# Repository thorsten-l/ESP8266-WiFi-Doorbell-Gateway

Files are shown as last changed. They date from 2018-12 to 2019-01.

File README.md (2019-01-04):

# ESP8266-WiFi-Doorbell-Gateway
A gateway for your doorbell button ;-)

## Screenshots
Find screenshots of the web interface in the [docs](https://github.com/thorsten-l/ESP8266-WiFi-Doorbell-Gateway/tree/master/docs) directory.

## Schematic diagrams and PCB files
Find schematic diagrams and pcb files in the [kicad](https://github.com/thorsten-l/ESP8266-WiFi-Doorbell-Gateway/tree/master/kicad) directory.

## Precompiled Firmware
Find the precompiled firmware in the [firmware](https://github.com/thorsten-l/ESP8266-WiFi-Doorbell-Gateway/tree/master/firmware) directory.

## Compile
This is a [PlatformIO](https://platformio.org/) project.

## Firmware Reset
1. Power on the WiFi Doorbell Gateway
2. Press down and hold the Power-Button during the first 5s
3. Release Power-Button when the WiFi LED starts rapidly fast blinking
4. The firmware reset ends after about 30s indicated by a permanent WiFi LED on.

## Default Settings
After a firmware reset the following values are set.

| | value | description |
|----|---|---|
| WiFi SSID | DoorbellGW-`esp id` | SSID in accesspoint mode |
| IP Address | 192.168.192.1 | ip address in accesspoint mode |
| Admin password | admin | Setup admin password |
| OTA Hostname | doorbell-gateway-1 | *O*ver *T*he *A*ir hostname |
| OTA Password | otapass | OTA firmware upload password |
| OpenHAB Callback Enabled | **false** | |
| OpenHAB Version | 1 | Callback for OpenHAB version 1 or 2 |
| OpenHAB Item Name | DoorbellGateway1 | |
| OpenHAB Host | 192.168.1.1 | |
| OpenHAB Port | 80 | |
| OpenHAB Use Authentication | false | |
| OpenHAB User | user |  |
| OpenHAB Password | password | |
| MQTT Enabled | **false** |  |
| MQTT ClientId | DoorbellGateway1 |  |
| MQTT Host | 192.168.1.1 | |
| MQTT Port | 80 | |
| MQTT Use Authentication | false | |
| MQTT User | user |  |
| MQTT Password | password | |
| MQTT Out Topic | doorbell1/out | sending callback |
| Syslog Enabled | **false** |  |
| Syslog Host | 192.168.1.1 | |
| Syslog Port (TCP) | 80 | |
| Syslog App Name | gateway-doorbell |  |

## Documentation
- Find screenshots of the web-pages [here](https://github.com/thorsten-l/ESP8266-WiFi-Doorbell-Gateway/tree/master/docs)

## Hardware
- [WEMOS D1 mini](https://wiki.wemos.cc/products:d1:d1_mini)

## References
- [PlatformIO](https://platformio.org/)
- [Arduino core for ESP8266 WiFi chip](https://github.com/esp8266/Arduino)
- [Async TCP Library for ESP8266](https://github.com/me-no-dev/ESPAsyncTCP)
- [Async Web Server for ESP8266 and ESP32](https://github.com/me-no-dev/ESPAsyncWebServer)
- [Arduino-pubsubclient - A client library for the ESP8266 that provides support for MQTT](https://github.com/heman4t/Arduino-pubsubclient)
- [Pure.CSS - A nice CSS, as GZIP it is less than 4k so it is useful for embedded devices](https://purecss.io/)

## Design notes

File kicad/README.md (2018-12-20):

# Schematic Diagram and PCB files

## Program
These files are created with [KiCad EDA](http://kicad-pcb.org/).

## Schematic Diagrams
- [WiFi Doorbell Gateway](https://github.com/thorsten-l/ESP8266-WiFi-Doorbell-Gateway/blob/master/kicad/wifidoorbell/WifiDoorBell-D1-mini.pdf)
- [WiFi LED Button](https://github.com/thorsten-l/ESP8266-WiFi-Doorbell-Gateway/blob/master/kicad/wifiledbutton/WifiLedButton.pdf)

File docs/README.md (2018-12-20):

# Documentation
## Screenshots
### Home Page
Klick on top right bars to open menu.
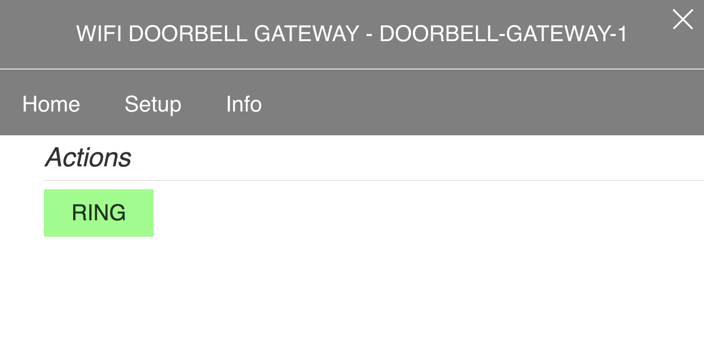
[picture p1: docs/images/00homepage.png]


### Setup Page

Admin password
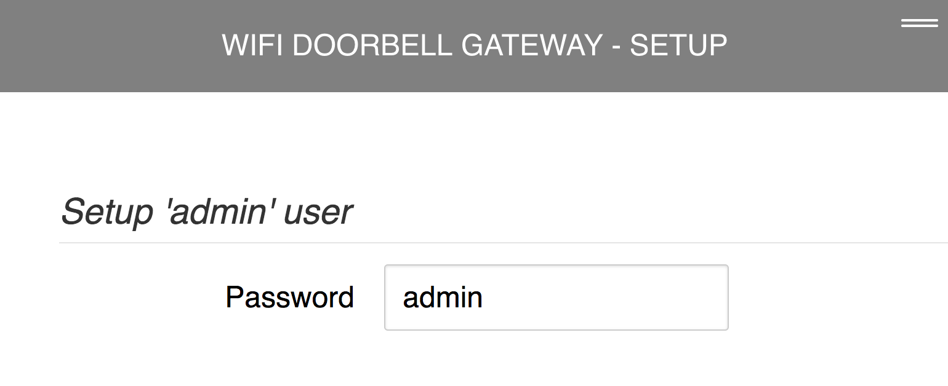
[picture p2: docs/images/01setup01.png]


Wifi Settings
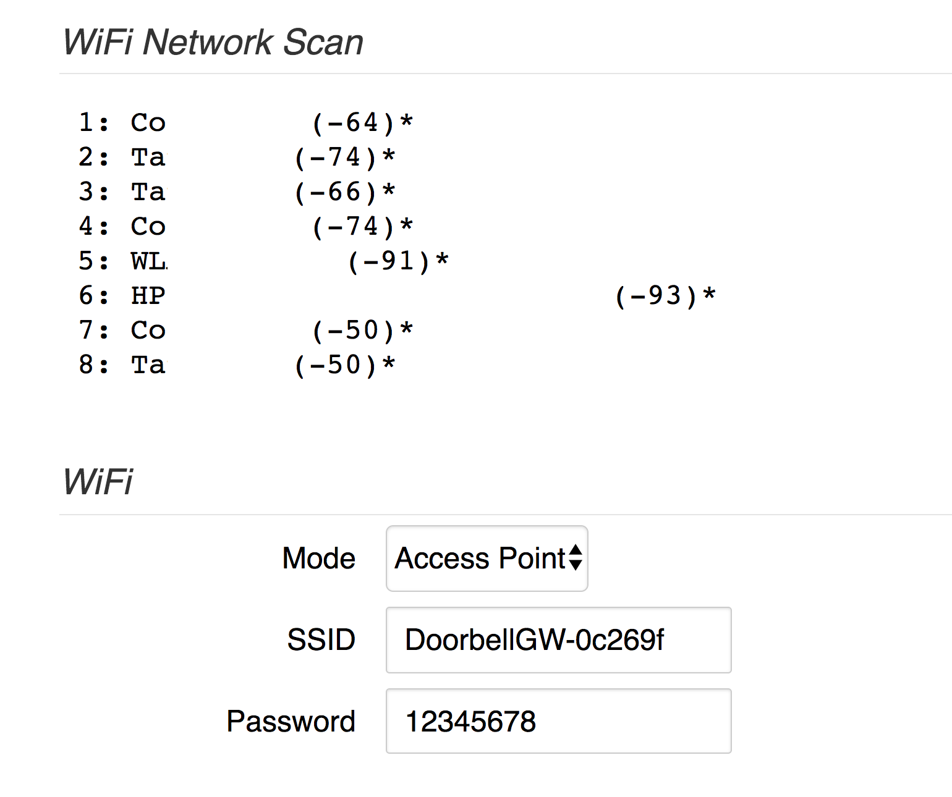
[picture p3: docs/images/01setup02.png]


Network Settings
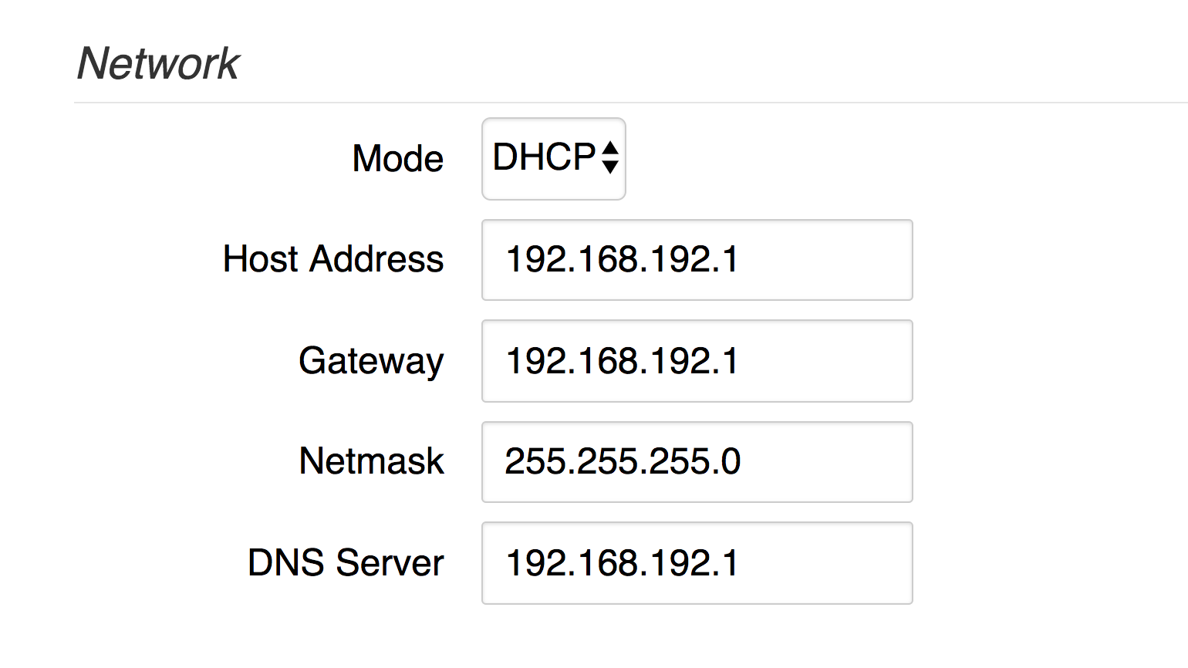
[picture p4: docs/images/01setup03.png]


OTA Settings
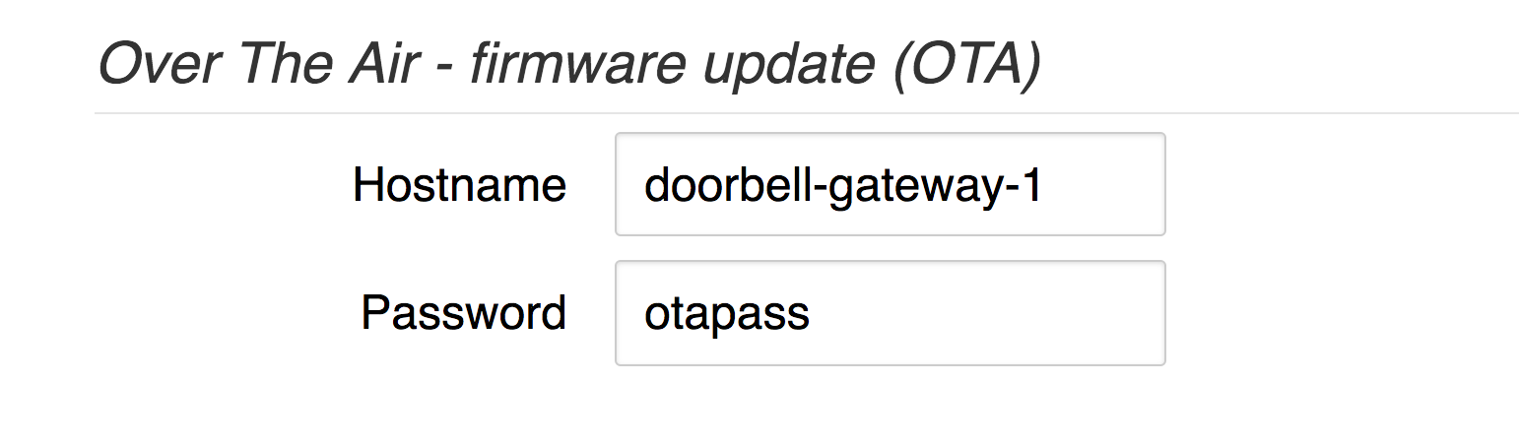
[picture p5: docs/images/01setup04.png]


OpenHAB Settings
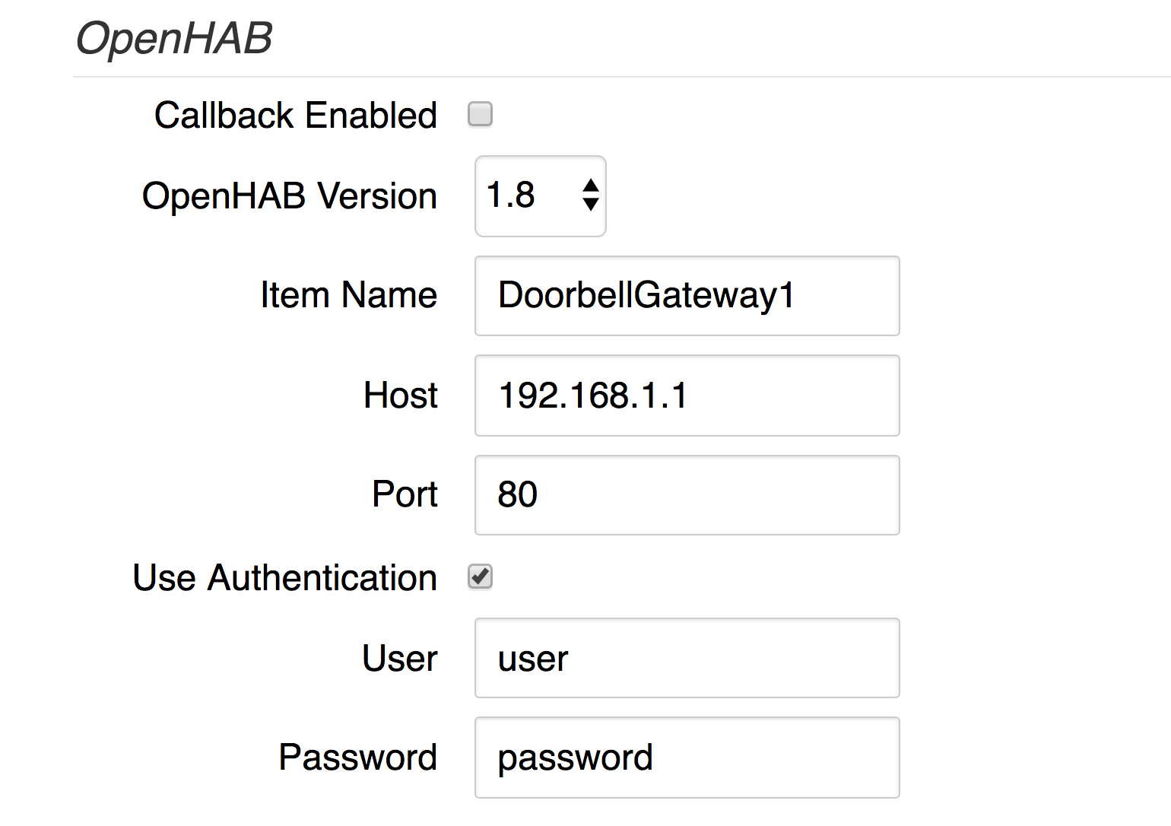
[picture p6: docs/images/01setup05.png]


MQTT Settings
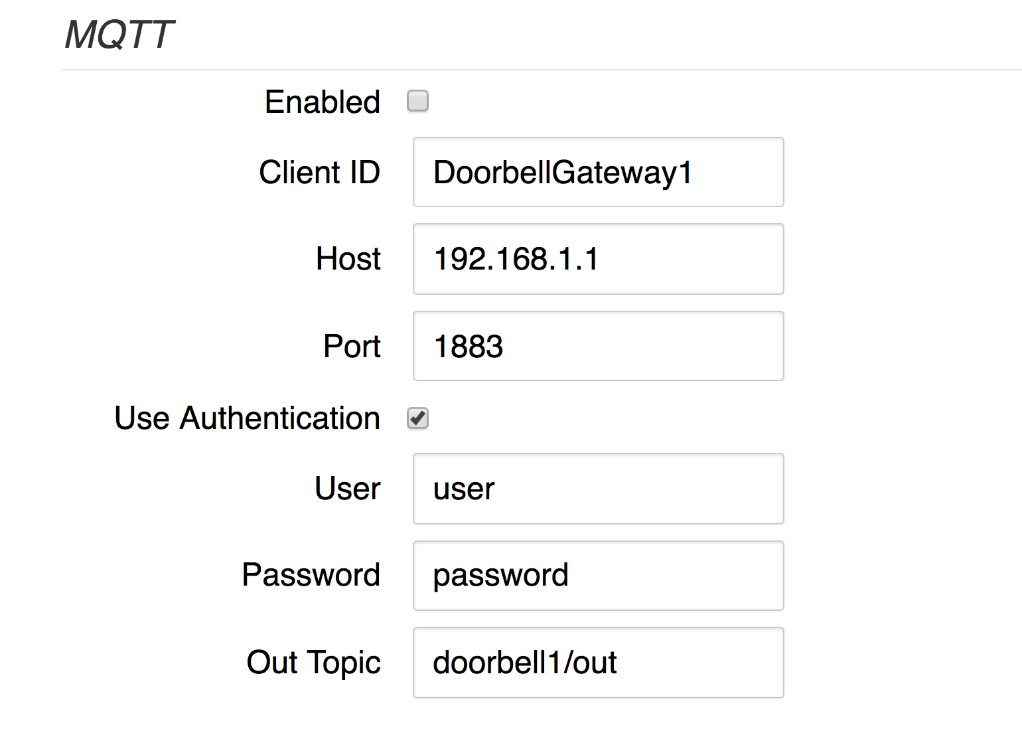
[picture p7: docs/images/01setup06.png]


Syslog Settings
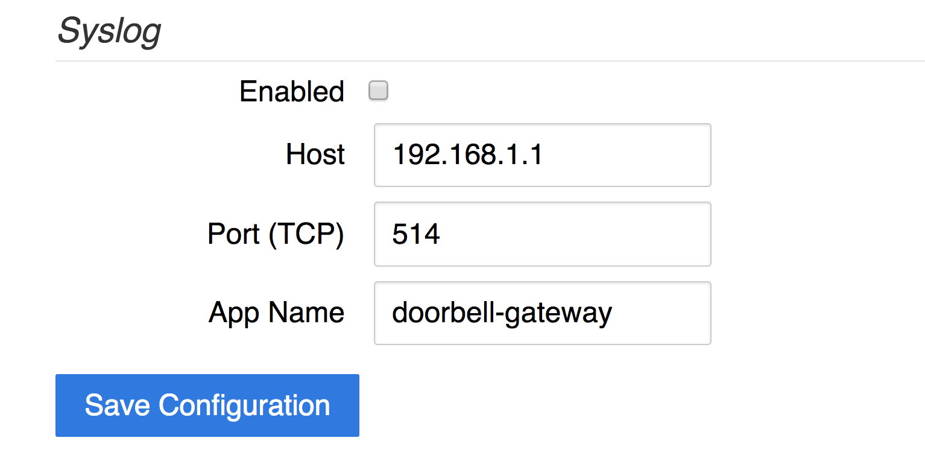
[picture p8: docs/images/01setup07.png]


## Info Page
Application, RESTful and Build information
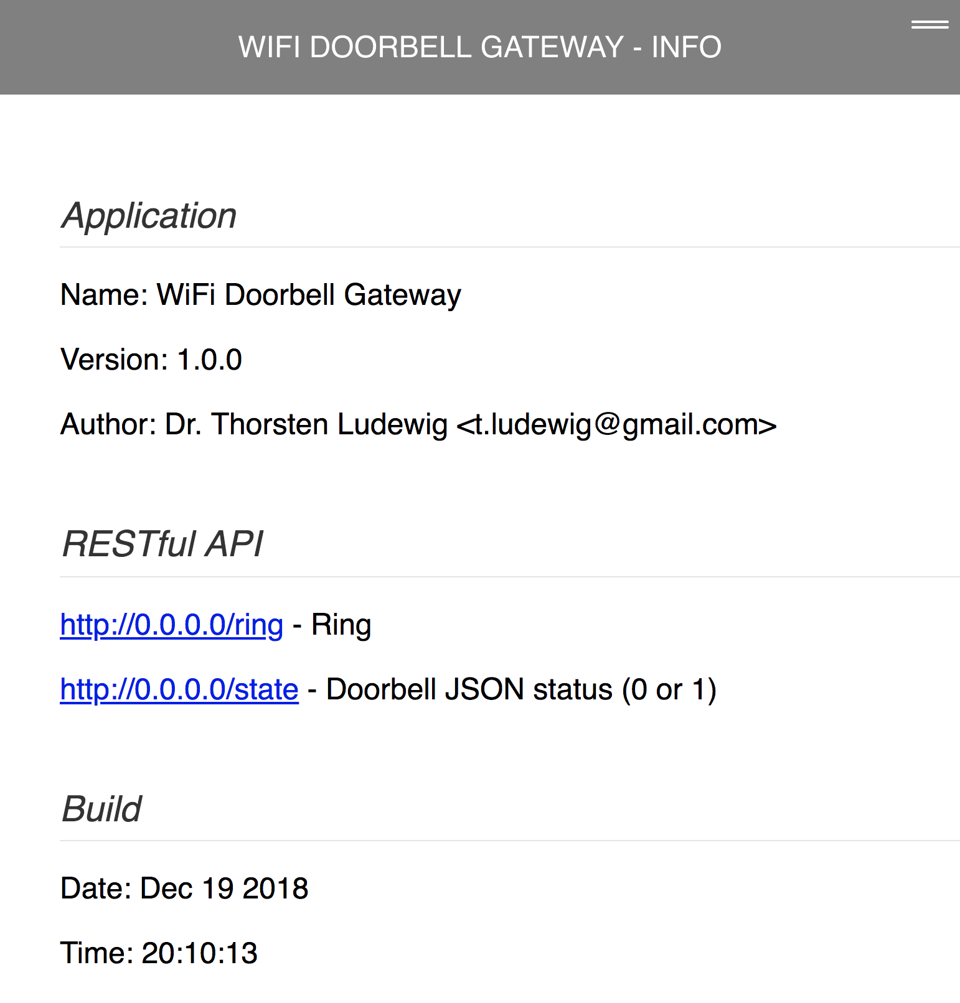
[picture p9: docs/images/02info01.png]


Services information
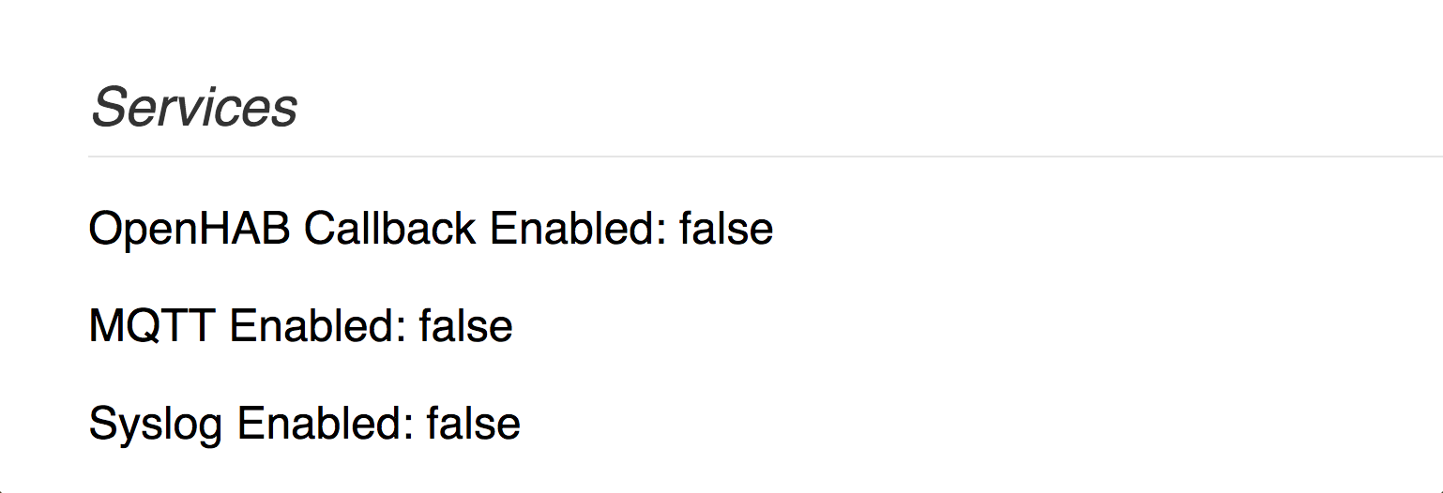
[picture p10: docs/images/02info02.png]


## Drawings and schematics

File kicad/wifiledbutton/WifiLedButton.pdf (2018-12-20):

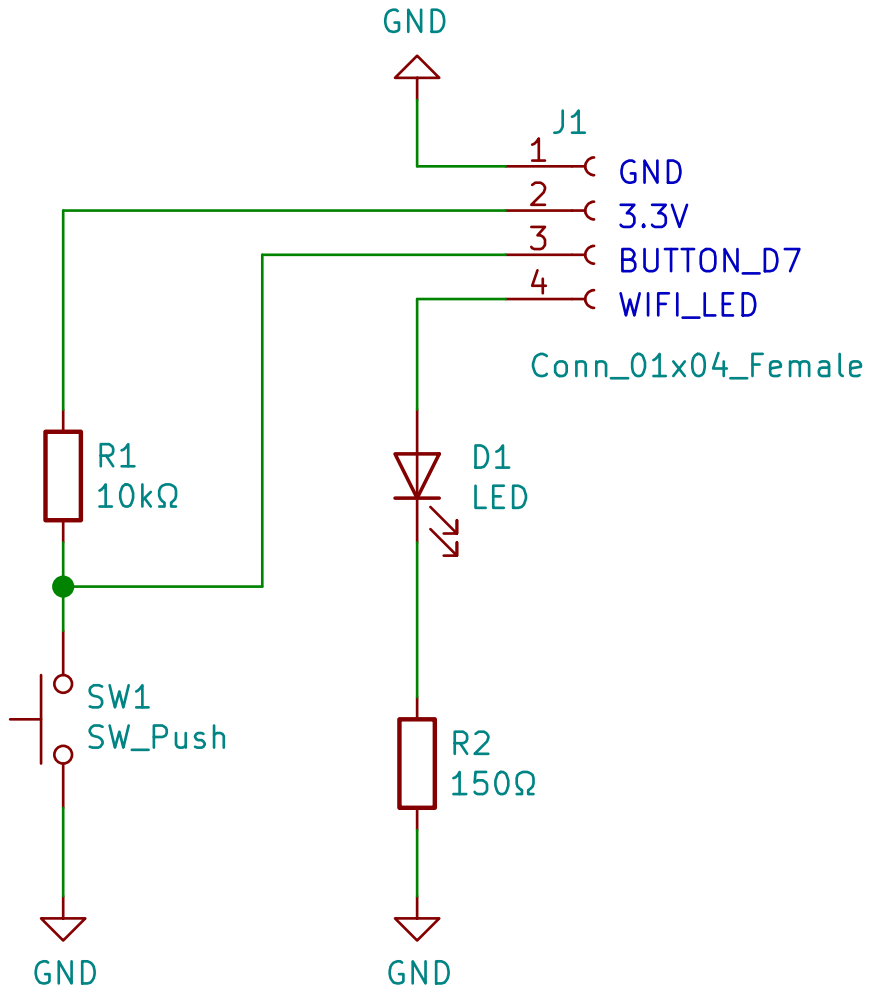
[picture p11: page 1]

File: WifiLedButton.sch Sheet: / Dr.-Ing. Thorsten Ludewig D1
LED

Id: 1/1 Title: Wifi LED Button

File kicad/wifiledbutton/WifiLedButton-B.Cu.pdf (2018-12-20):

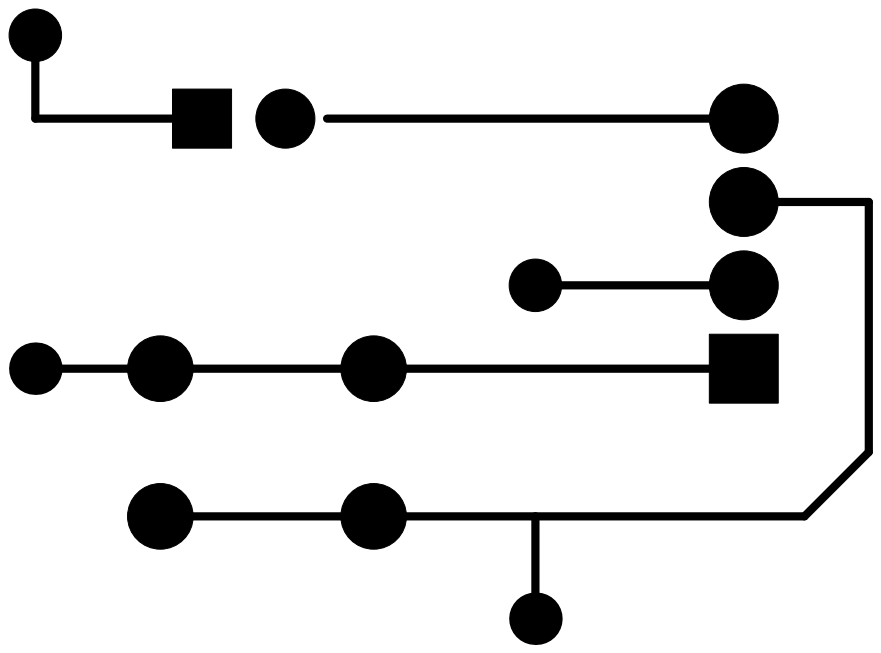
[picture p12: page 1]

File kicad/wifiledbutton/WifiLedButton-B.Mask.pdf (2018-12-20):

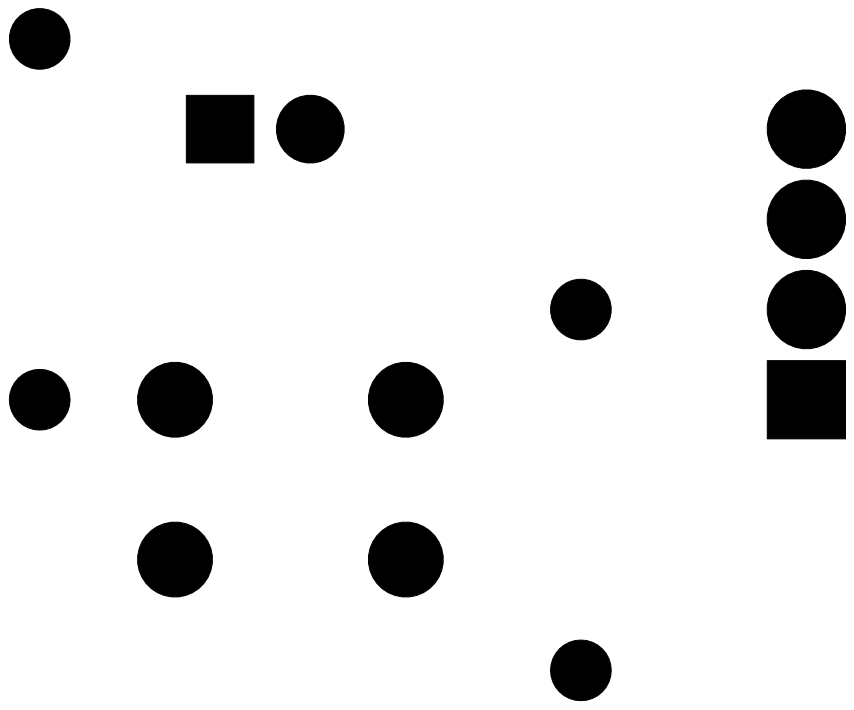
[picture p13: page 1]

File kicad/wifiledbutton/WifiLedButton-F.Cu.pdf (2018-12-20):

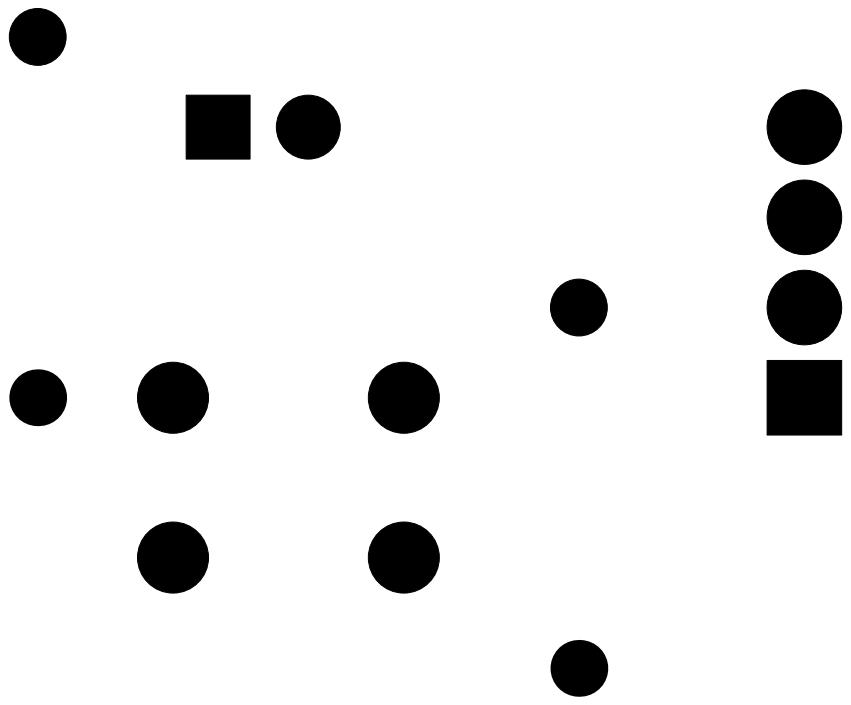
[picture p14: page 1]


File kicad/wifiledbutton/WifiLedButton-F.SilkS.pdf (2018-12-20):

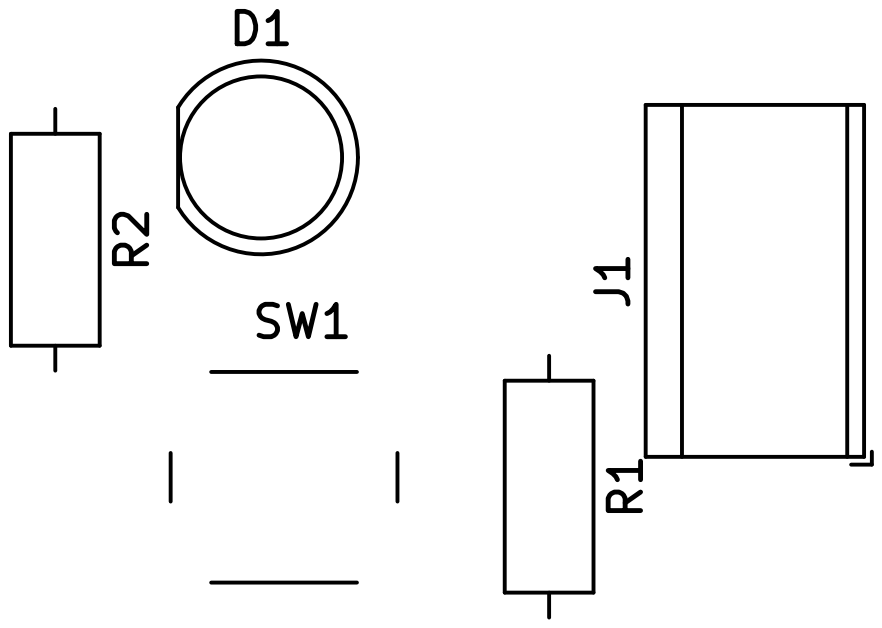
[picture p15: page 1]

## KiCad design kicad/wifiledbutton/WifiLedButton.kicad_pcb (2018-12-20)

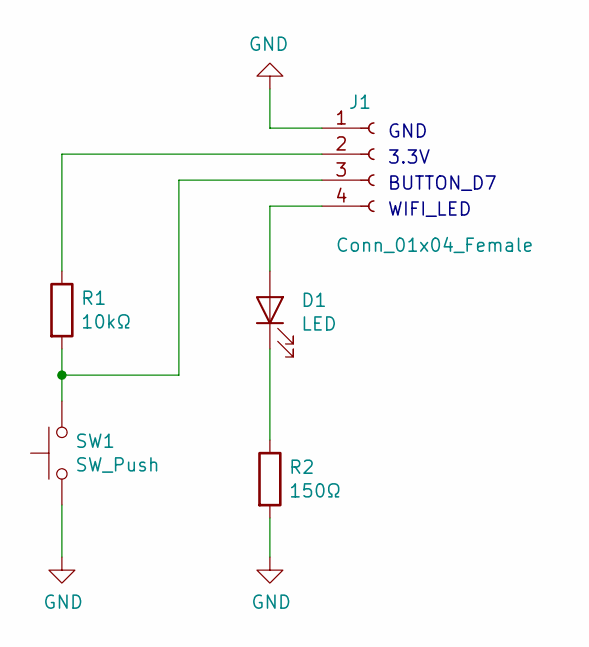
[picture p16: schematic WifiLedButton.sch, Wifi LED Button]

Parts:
D1: LED; LED_D5.0mm
J1: Conn_01x04_Female; TerminalBlock_TE_282834-4_1x04_P2.54mm_Horizontal
R1: 10kΩ; R_Axial_DIN0207_L6.3mm_D2.5mm_P10.16mm_Horizontal
R2: 150Ω; R_Axial_DIN0207_L6.3mm_D2.5mm_P10.16mm_Horizontal
SW1: SW_Push; SW_PUSH_6mm

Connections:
GND: J1.1, R2.2, SW1.1
unnamed: D1.1 (K), R2.1
unnamed: D1.2 (A), J1.4
unnamed: J1.2, R1.1
unnamed: J1.3, R1.2, SW1.2

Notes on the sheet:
GND
3.3V
BUTTON_D7
WIFI_LED

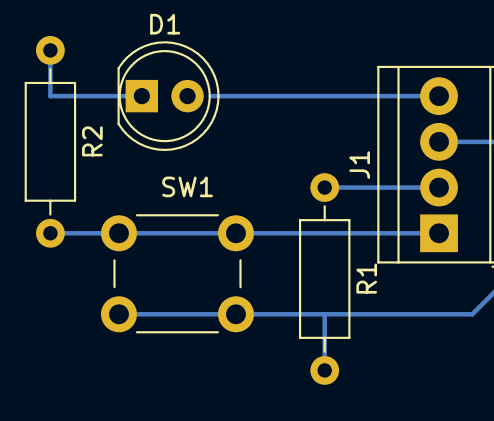
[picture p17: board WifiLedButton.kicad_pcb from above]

Board: 2 copper layers, 5 parts (0 on the bottom side), 5 nets.

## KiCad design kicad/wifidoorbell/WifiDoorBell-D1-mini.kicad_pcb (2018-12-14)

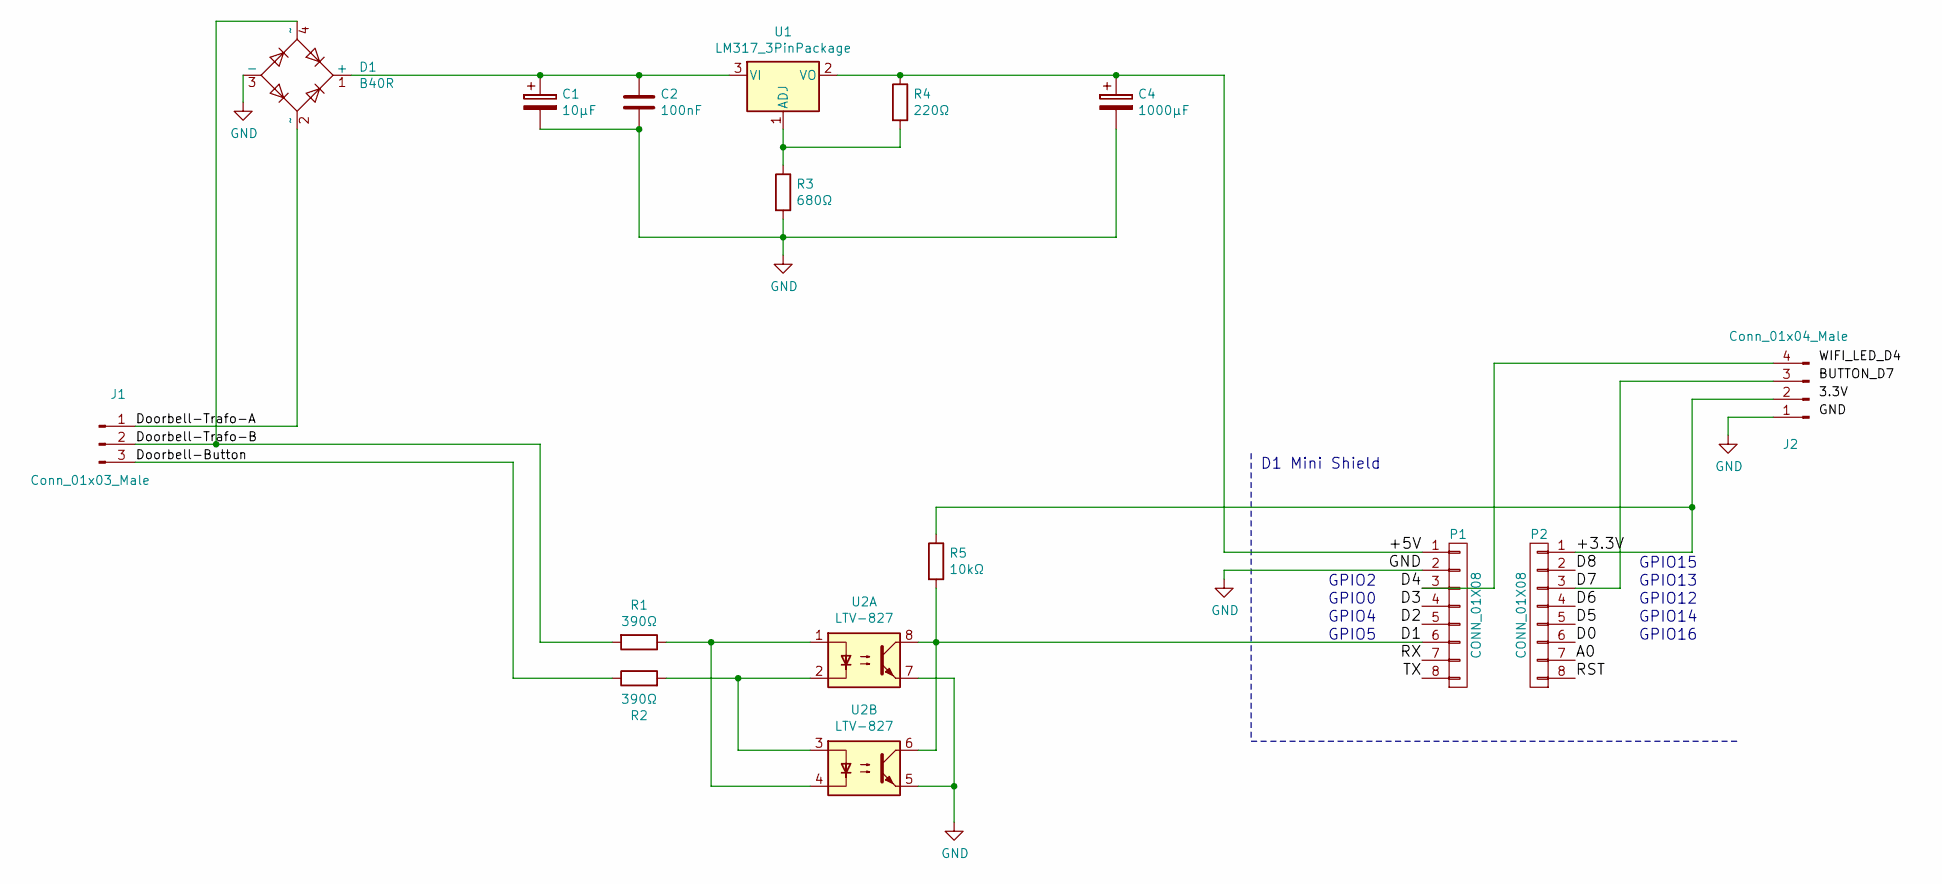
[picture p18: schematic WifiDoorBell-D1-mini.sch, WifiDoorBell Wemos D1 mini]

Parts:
C1: 10µF; CP_Radial_D5.0mm_P2.50mm
C2: 100nF; C_Rect_L9.0mm_W2.5mm_P7.50mm_MKT
C4: 1000µF; CP_Radial_D5.0mm_P2.50mm
D1: B40R; Diode_Bridge_Round_D9.0mm
J1: Conn_01x03_Male; TerminalBlock_TE_282834-3_1x03_P2.54mm_Horizontal
J2: Conn_01x04_Male; TerminalBlock_TE_282834-4_1x04_P2.54mm_Horizontal
P1, P2: CONN_01X08; D1_mini_Pin_Header
R1, R2: 390Ω; R_Axial_DIN0204_L3.6mm_D1.6mm_P2.54mm_Vertical
R3: 680Ω; R_Axial_DIN0204_L3.6mm_D1.6mm_P2.54mm_Vertical
R4: 220Ω; R_Axial_DIN0204_L3.6mm_D1.6mm_P2.54mm_Vertical
R5: 10kΩ; R_Axial_DIN0204_L3.6mm_D1.6mm_P2.54mm_Vertical
U1: LM317_3PinPackage; TO-220-3_Vertical
U2: LTV-827; DIP-8_W7.62mm

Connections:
/+3.3V: J2.2, P2.1, R5.1
/+5V: C4.1, P1.1, R4.1, U1.2 (VO)
/A0: P2.7
/D0: P2.6
/D1: P1.6, R5.2, U2.6, U2.8
/D2: P1.5
/D3: P1.4
/D4: J2.4, P1.3
/D5: P2.5
/D6: P2.4
/D7: J2.3, P2.3
/D8: P2.2
/Doorbell-Button: J1.3, R2.1
/Doorbell-Trafo-A: D1.2 (~~), J1.1
/Doorbell-Trafo-B: D1.4 (~~), J1.2, R1.2
/RST: P2.8
/RX: P1.7
/TX: P1.8
GND: C1.2, C2.2, C4.2, D1.3 (-), J2.1, P1.2, R3.2, U2.5, U2.7
unnamed: C1.1, C2.1, D1.1 (+), U1.3 (VI)
unnamed: R1.1, U2.1, U2.4
unnamed: R2.2, U2.2, U2.3
unnamed: R3.1, R4.2, U1.1 (ADJ)

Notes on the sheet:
GPIO2
GPIO0
GPIO4
GPIO5
GPIO15
GPIO13
GPIO12
GPIO14
GPIO16
D1 Mini Shield

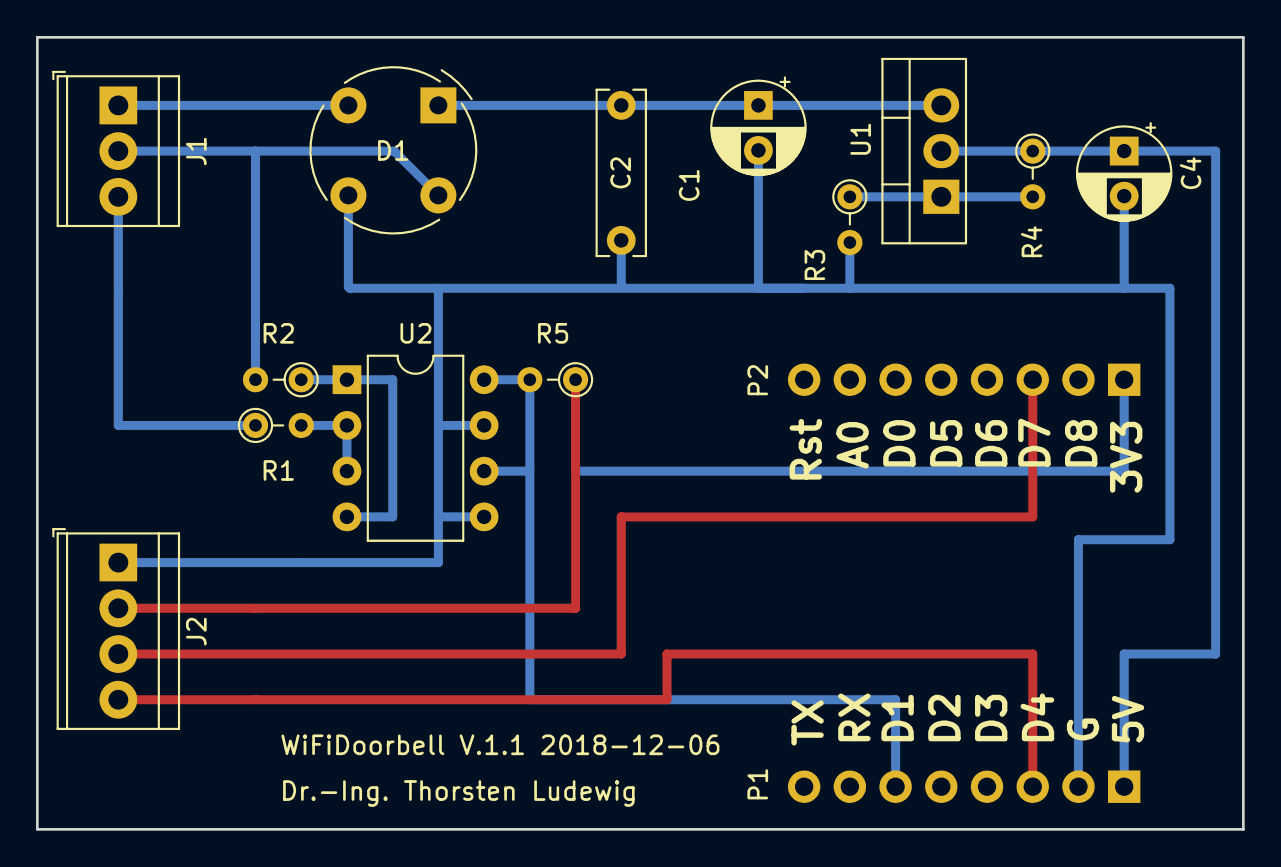
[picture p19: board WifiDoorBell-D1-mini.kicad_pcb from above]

Board: 2 copper layers, 67.0 x 44.0 mm, 15 parts (0 on the bottom side), 13 nets.

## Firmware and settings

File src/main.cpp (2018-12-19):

#include <App.hpp>
#include <Arduino.h>
#include <ESP8266WiFi.h>
#include <MqttHandler.hpp>
#include <OpenHabHandler.hpp>
#include <OtaHandler.hpp>
#include <Syslog.hpp>
#include <WebHandler.hpp>
#include <WifiHandler.hpp>

time_t lifeTicker;
time_t maxLoopTime;
time_t lastLoopTimestamp;
time_t thisLoopTimestamp;
time_t debounceTimestamp;
time_t buttonPressed0Timestamp;

volatile bool buttonPressed0;
volatile bool buttonPressed;
volatile bool showPressingDuration;

bool firstRun;

void ringButtonPressed()
{
  time_t cm = millis();

  if (!buttonPressed && (cm - debounceTimestamp > 1000)) // button debouncing
  {
    buttonPressed0 = true;
    buttonPressed0Timestamp = cm;
  }

  if (buttonPressed0 && (cm - buttonPressed0Timestamp) >= 35)
  {
    buttonPressed = true;
    buttonPressed0 = false;
  }

  showPressingDuration = true;
  debounceTimestamp = millis();
}

void setup()
{
  buttonPressed0 = false;
  buttonPressed = false;
  showPressingDuration = false;
  firstRun = true;
  app.setup();
  app.writeConfig();
  app.printConfig();
  wifiHandler.setup();

  attachInterrupt(digitalPinToInterrupt(RING_BUTTON), &ringButtonPressed,
                  FALLING);

  maxLoopTime = 0l;
  lifeTicker = lastLoopTimestamp = millis();
}

void loop()
{
  thisLoopTimestamp = millis();
  maxLoopTime = max(maxLoopTime, thisLoopTimestamp - lastLoopTimestamp);
  lastLoopTimestamp = thisLoopTimestamp;

  if (buttonPressed0 && (thisLoopTimestamp - debounceTimestamp) >= 200)
  {
    buttonPressed = false;
    buttonPressed0 = false;
    syslog.logInfo("Ringbutton pressed to short");
  }

  if (showPressingDuration && (thisLoopTimestamp - debounceTimestamp) >= 1000)
  {
    showPressingDuration = false;
    syslog.logInfo("button pressing time in ms:",
                   (int)(debounceTimestamp - buttonPressed0Timestamp));
  }

  if (buttonPressed)
  {
    buttonPressed = false;
    LOG0("Button pressed...\n");
    syslog.logInfo("The doorbell is ringing.");
    openHabHandler.sendValue("ON");
    mqttHandler.sendValue("ON");
  }

  if ((thisLoopTimestamp - lifeTicker) >= 120000)
  {
    LOG1("max loop time = %ld\n", maxLoopTime);
    LOG1("wifi is connected %d\n", wifiHandler.isConnected());
    maxLoopTime = 0l;
    lifeTicker = thisLoopTimestamp;
    syslog.logInfo("i'm alive");
  }

  if (wifiHandler.handle(thisLoopTimestamp))
  {
    otaHandler.handle();
    webHandler.handle();
    mqttHandler.handle();

    if (firstRun)
    {
      syslog.logInfo(APP_NAME ", Version " APP_VERSION ", by " APP_AUTHOR);
      syslog.logInfo("Build date: " __DATE__ " " __TIME__);
      firstRun = false;
    }
  }

  app.handle();
}

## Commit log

2018-12-14 pcb1 files
2018-12-20 WiFi LED Button
    [WifiLedButton-B.Cu.gbr, WifiLedButton-B.Mask.gbr, WifiLedButton-B.Paste.gbr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]
2019-01-04 Link to Screenshots and Schematic diagrams added
